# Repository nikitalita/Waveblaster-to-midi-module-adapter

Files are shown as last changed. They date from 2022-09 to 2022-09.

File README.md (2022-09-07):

# Waveblaster Breakout Card
A waveblaster breakout card to enable the use of external midi modules on sound cards:
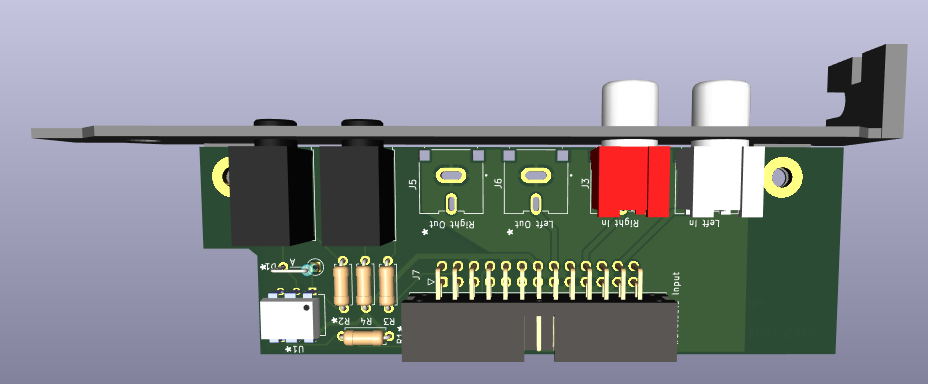
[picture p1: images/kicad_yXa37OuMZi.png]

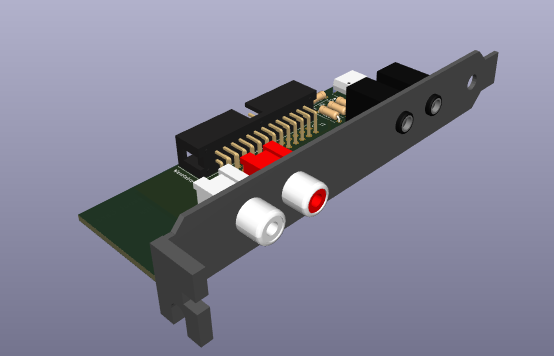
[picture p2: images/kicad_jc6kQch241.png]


Tested and working; here's the BOM:

| Id | Designator | Package | Quantity | Designation | Mouser: |
| ---- | --- | --- | --- | --- | --- |
| 1 | J7 | IDC-Header_2x13_P2.54mm_Horizontal-reversed | 1 | Wavetable Input | [5103310-6](https://www.mouser.com/ProductDetail/TE-Connectivity/5103310-6) |
| 2 | J1 | Jack_3.5mm_CUI_SJ1-3533NG_Horizontal | 1 | Midi Out | [490-SJ1-3533NG](https://www.mouser.com/ProductDetail/490-SJ1-3533NG) |
| 3 | R4,R3 | 220R THT resistor | 2 | 220R | |
| 4 | J3 | CUI_RCJ-042 | 1 | Right In | [490-RCJ-042](https://www.mouser.com/ProductDetail/490-RCJ-042) |
| 5 | J4 | CUI_RCJ-043 | 1 | Left In | [490-RCJ-043](https://www.mouser.com/ProductDetail/490-RCJ-043) |

For the header, you also can just use 2.54mm pitch double row right angle header pins. For the resistors, just buy a through-hole resistor sample book on Amazon or something.

If you want to add on the midi in port (most sound cards do not have this connected), add:

- 1x H11L1M optocoupler : https://www.mouser.com/ProductDetail/onsemi-Fairchild/H11L1M
- 1x 220 Ohm THT Resistor
- 1x 280 Ohm THT Resistor
- 1x 1N4148 THT Diode: https://www.mouser.com/ProductDetail/onsemi-Fairchild/1N4148

It's not advised to add on the audio output ports (for audio input into the synth), as only ONE sound card is known to make use of these: the MediaTriX AudioTriX 3D-XG, and it is very rare.

For the MIDI ports, you want a Type "A" 3.5mm to DIN adapter, like this one: https://www.amazon.com/ZAWDIO-Breakout-LittleBits-Female-Electribe/dp/B08WHSP7ZL/
Make sure that it is not Type "B", as this type will not work.

For the ribbon cable to connect the waveblaster header, Just use a 26 pin IDC cable. This one worked well for me: https://www.amazon.com/gp/product/B01AG9GXV4/ref=ppx_yo_dt_b_asin_title_o02_s00?ie=UTF8&psc=1

For the bracket, use the stencil file in bracket to 3D print it out. If you decide to make a metal one, be sure to add insulating rubber rings between the ports and the bracket, as this board is not intended to be grounded to the case.

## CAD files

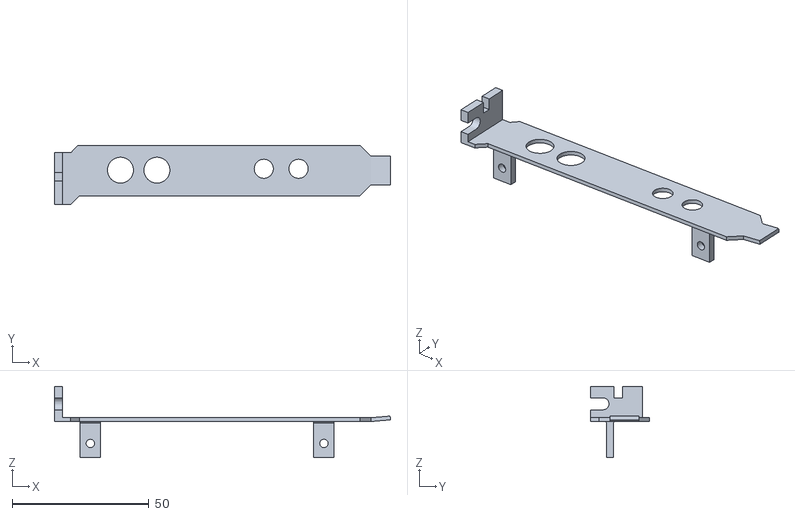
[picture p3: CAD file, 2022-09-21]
bracket/bracket.stl
122.8 x 21.6 x 26.0

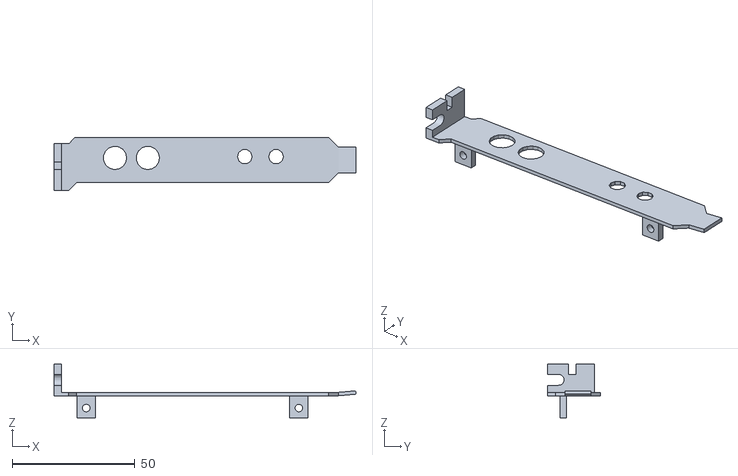
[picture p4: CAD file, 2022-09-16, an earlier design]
bracket/bracket-old.stl
122.8 x 21.6 x 21.8

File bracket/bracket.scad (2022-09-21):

resolution=32; // $fn
low_profile=0; // [0:false, 1:true]
bracket_thickness = 1.4; // base bracket depth

//Some 3d printers may have trouble with this, disable it if yours does.
angled_bottom_tab = 1; // [0:false, 1:true]
decorative_hole=0; // [0:false, 1:true]
// This puts the tabs at the top rather than the bottom, and hole y-offsets are adjusted accordingly
isa_slot=0; // [0:false, 1:true]
// This is used to calculate the y-offsets of the holes if the screw mount tabs are on the bottom
pcb_thickness=1.6;

top_tab_thickness = 3;

/* [Screw mount tabs] */

first_screw_tab_enabled = 1; // [0:false, 1:true]
second_screw_tab_enabled = 1; // [0:false, 1:true]
screw_mounts_on_bottom_of_pcb = 0; // [0:false, 1:true]
screw_mount_width = 7.5;
screw_mount_depth = 2.5;
screw_mount_hole_r = 1.55; // m3 bolt
screw_mount_thread_distance_base = 8;
screw_mount_inset_r = 2.9; // m3 bolt head
screw_mount_inset_depth = 0;
screw_mount_caulking = 0.5;

first_mount_x = 10.11;
mount_hole_distance = 85.4;
// If on top of the PCB, it is recommended to have this be at least the thickness of the PCB
screw_mount_y = 2.7;
second_mount_x = first_mount_x + mount_hole_distance;

/* [Round Holes] */
hole_1_enabled = 1; // [0:false, 1:true]
// X is offset from the first screw hole (i.e. the screw hole closest to the case mount cutout)
hole_1_x = 11.01;
// Y is offset from top of pcb
hole_1_y = 6.7;
hole_1_d = 9.5;

hole_2_enabled = 1; // [0:false, 1:true]
hole_2_x = 24.34;
hole_2_y = 6.7;
hole_2_d = 9.5;

hole_3_enabled = 1; // [0:false, 1:true]
hole_3_x = 63.41;
hole_3_y = 7.2;
hole_3_d = 6;

hole_4_enabled = 1; // [0:false, 1:true]
hole_4_x = 76.12;
hole_4_y = 7.2;
hole_4_d = 6;

hole_5_enabled = 0; // [0:false, 1:true]
hole_5_x = 37.69;
hole_5_y = 6.7;
hole_5_d = 9.5;

hole_6_enabled = 0; // [0:false, 1:true]
hole_6_x = 51.04;
hole_6_y = 6.7;
hole_6_d = 9.5;

/* [Rectangular Holes] */
// hole is at center of x,y positions
rectangular_hole_1_enabled = 0; // [0:false, 1:true]
// X is offset from the first screw hole (i.e. the screw hole closest to the case mount cutout)
rectangular_hole_1_x = 11.01;
// Y is offset from top of pcb
rectangular_hole_1_y = 6.5;
rectangular_hole_1_w = 10.5;
rectangular_hole_1_h = 10.5;

rectangular_hole_2_enabled = 0; // [0:false, 1:true]
rectangular_hole_2_x = 24.34;
rectangular_hole_2_y = 6.5;
rectangular_hole_2_w = 10.5;
rectangular_hole_2_h = 10.5;

rectangular_hole_3_enabled = 0; // [0:false, 1:true]
rectangular_hole_3_x = 63.41;
rectangular_hole_3_y = 7;
rectangular_hole_3_w = 10.5;
rectangular_hole_3_h = 10.5;

rectangular_hole_4_enabled = 0; // [0:false, 1:true]
rectangular_hole_4_x = 76.12;
rectangular_hole_4_y = 7;
rectangular_hole_4_w = 10.5;
rectangular_hole_4_h = 10.5;

rectangular_hole_5_enabled = 0; // [0:false, 1:true]
rectangular_hole_5_x = 37.69;
rectangular_hole_5_y = 6.5;
rectangular_hole_5_w = 10.5;
rectangular_hole_5_h = 10.5;

rectangular_hole_6_enabled = 0; // [0:false, 1:true]
rectangular_hole_6_x = 51.04;
rectangular_hole_6_y = 6.5;
rectangular_hole_6_w = 10.5;
rectangular_hole_6_h = 10.5;
// values taken from https://content.norcomp.net/rohspdfs/Connectors/PanelCutOuts/Panel_Cutout_D-Sub-Single.pdf

/* [D-Sub holes (Serial/VGA/Gameport)] */
// hole is at center of x,y positions
dsub_hole_1_type = 0; // [0:None, 15.46:DB-9(VGA/Serial), 23.79:DB-15(Gameport), 37.51:DB-25(Parallel)]
// X is offset from the first screw hole (i.e. the screw hole closest to the case mount cutout)
dsub_hole_1_x = 37.6;
// Y is offset from top of pcb
dsub_hole_1_y = 7.1;
dsub_hole_1_invert = 0; // [0:false, 1:true]

dsub_hole_2_type = 0; // [0:None, 15.46:DB-9(VGA/Serial), 23.79:DB-15(Gameport), 37.51:DB-25(Parallel)]
dsub_hole_2_x = 37.6;
dsub_hole_2_y = 7.1;
dsub_hole_2_invert = 0; // [0:false, 1:true]

dsub_hole_3_type = 0; // [0:None, 15.46:DB-9(VGA/Serial), 23.79:DB-15(Gameport), 37.51:DB-25(Parallel)]
dsub_hole_3_x = 37.6;
dsub_hole_3_y = 7.1;
dsub_hole_3_invert = 0; // [0:false, 1:true]

/* [DVI Hole]] */

dvi_hole_enabled = 0; // [0:false, 1:true]
dvi_hole_x = 37.6;
dvi_hole_y = 6;
dvi_hole_invert = 0; // [0:false, 1:true]


module __Customizer_Limit__ () {}  // This actually works
shown_by_customizer = 0; // [0:false, 1:true]

$fn = resolution;
bracket_width_length = low_profile? 71.46 : 112.78;
bracket_length = low_profile ? 79.20 : 120.02;
bracket_width = 18.42 + 0;
bottom_tab_width = 10.19 + 0;
bracket_bottom_tab_angle_length = (bracket_width - bottom_tab_width) / 2;

bracket_reinforce_width = bracket_width * .2;
bracket_reinforce_length = bracket_length * .78;

bracket_hole_dia = decorative_hole ? 4.75 : 0;
bracket_hole_distance = low_profile ? 66.19 : 107.01;

screw_mount_thread_distance = screw_mount_thread_distance_base + bracket_thickness;
screw_mount_length = screw_mount_thread_distance * 1.4 + bracket_thickness;

bracket_reinforce_depth = 0;
bracket_reinforce_offset_x = -6;
bracket_reinforce_offset_y = -5;

// top notch
notch_width = 2.54;
notch_length = 3.94-.86; // 3.94 - specified thickness of .86mm (vs actual thickness)

top_tab_width = 19.05; // had to fudge this
top_tab_length = 11.43;
top_tab_x = 0;
top_tab_y = 3.17; // 21.59 - 18.42
top_tab_screw_groove_dia = 4.42;
top_tab_screw_groove_fudge = -0.4; // kinda came out looking wrong so I'm faking it a bit here
top_tab_screw_groove_center = 3.18 + top_tab_screw_groove_fudge;
top_tab_screw_groove_distance = 6.35;
top_tab_screw_groove_translate_z = top_tab_length - top_tab_screw_groove_dia / 2 - top_tab_screw_groove_distance;

top_tab_useless_notch_length = 3.05;
top_tab_useless_notch_width = top_tab_screw_groove_distance - top_tab_screw_groove_dia / 2;
top_tab_useless_notch_z = top_tab_length - top_tab_useless_notch_width;
top_tab_useless_notch_y = top_tab_useless_notch_width / 2 + 8.05 - top_tab_useless_notch_length / 2;


module prism(l, w, h){
     polyhedron(
         points=[[0,0,0], [l,0,0], [l,w,0], [0,w,0], [0,w,h], [l,w,h]],
         faces=[[0,1,2,3],[5,4,3,2],[0,4,5,1],[0,3,4],[5,2,1]]
         );
}
// screw mounts
module screwmount(x) {
  
  translate([0, isa_slot? -screw_mount_y - screw_mount_depth : -bracket_width + screw_mount_y, 0]) // easier to be explicit here than factor it in the below statement
  translate([x - screw_mount_width / 2, bracket_width, -screw_mount_length + bracket_thickness])
    // cut out the threads
    difference() {
      union() {
        cube([screw_mount_width, screw_mount_depth, screw_mount_length]);
        //top caulking
        if ((isa_slot && bracket_width-screw_mount_y +screw_mount_caulking < bracket_width) || (!isa_slot &&  screw_mount_y + screw_mount_depth+ screw_mount_caulking < bracket_width)){
        difference(){
        translate([screw_mount_width, screw_mount_depth-.05, screw_mount_length-bracket_thickness-screw_mount_caulking +.05])
          rotate([90,0,180])
          prism(screw_mount_width,screw_mount_caulking+.05,screw_mount_caulking+.05);
        }
        }
        //bottom caulking
        if ((isa_slot && bracket_width-screw_mount_y -screw_mount_depth -screw_mount_caulking > 0) || (!isa_slot && screw_mount_y - screw_mount_caulking > 0)){
        translate([0, 0, screw_mount_length-bracket_thickness-screw_mount_caulking +.05])
          rotate([90,0,0])
          prism(screw_mount_width,screw_mount_caulking+.05,screw_mount_caulking+.05);
        }        
      }
       translate([screw_mount_width / 2, -2, screw_mount_length - screw_mount_thread_distance])
         rotate([0, 90, 90]) cylinder(r=screw_mount_hole_r, h=10, $fn=20);
      //inset
      translate([screw_mount_width / 2, ((isa_slot && screw_mounts_on_bottom_of_pcb) || (!isa_slot && !screw_mounts_on_bottom_of_pcb))?(screw_mount_depth - screw_mount_inset_depth + 0.01):(-0.01),
        screw_mount_length - screw_mount_thread_distance])
          rotate([0, 90, 90])
          cylinder(r=screw_mount_inset_r, h=screw_mount_inset_depth, $fn=20);
    }
}

module translate_hole(hole_x,hole_y){
  y_offset_b = screw_mounts_on_bottom_of_pcb ? pcb_thickness + screw_mount_depth : 0;
  y_offset = !isa_slot ? 
    hole_y + screw_mount_y + y_offset_b
    : bracket_width - (hole_y + screw_mount_y + y_offset_b);
  translate([first_mount_x+ hole_x, y_offset, -bracket_thickness])
    children();
}
module round_hole(hole_x,hole_y,hole_d){
  translate_hole(hole_x,hole_y)
    cylinder(10,hole_d/2,hole_d/2);
}
module rectangular_hole(hole_x,hole_y,hole_w,hole_h){
  translate_hole(hole_x,hole_y)
    cube([10, hole_w, hole_h], center=true);
}
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

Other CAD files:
kicad/bracket.step

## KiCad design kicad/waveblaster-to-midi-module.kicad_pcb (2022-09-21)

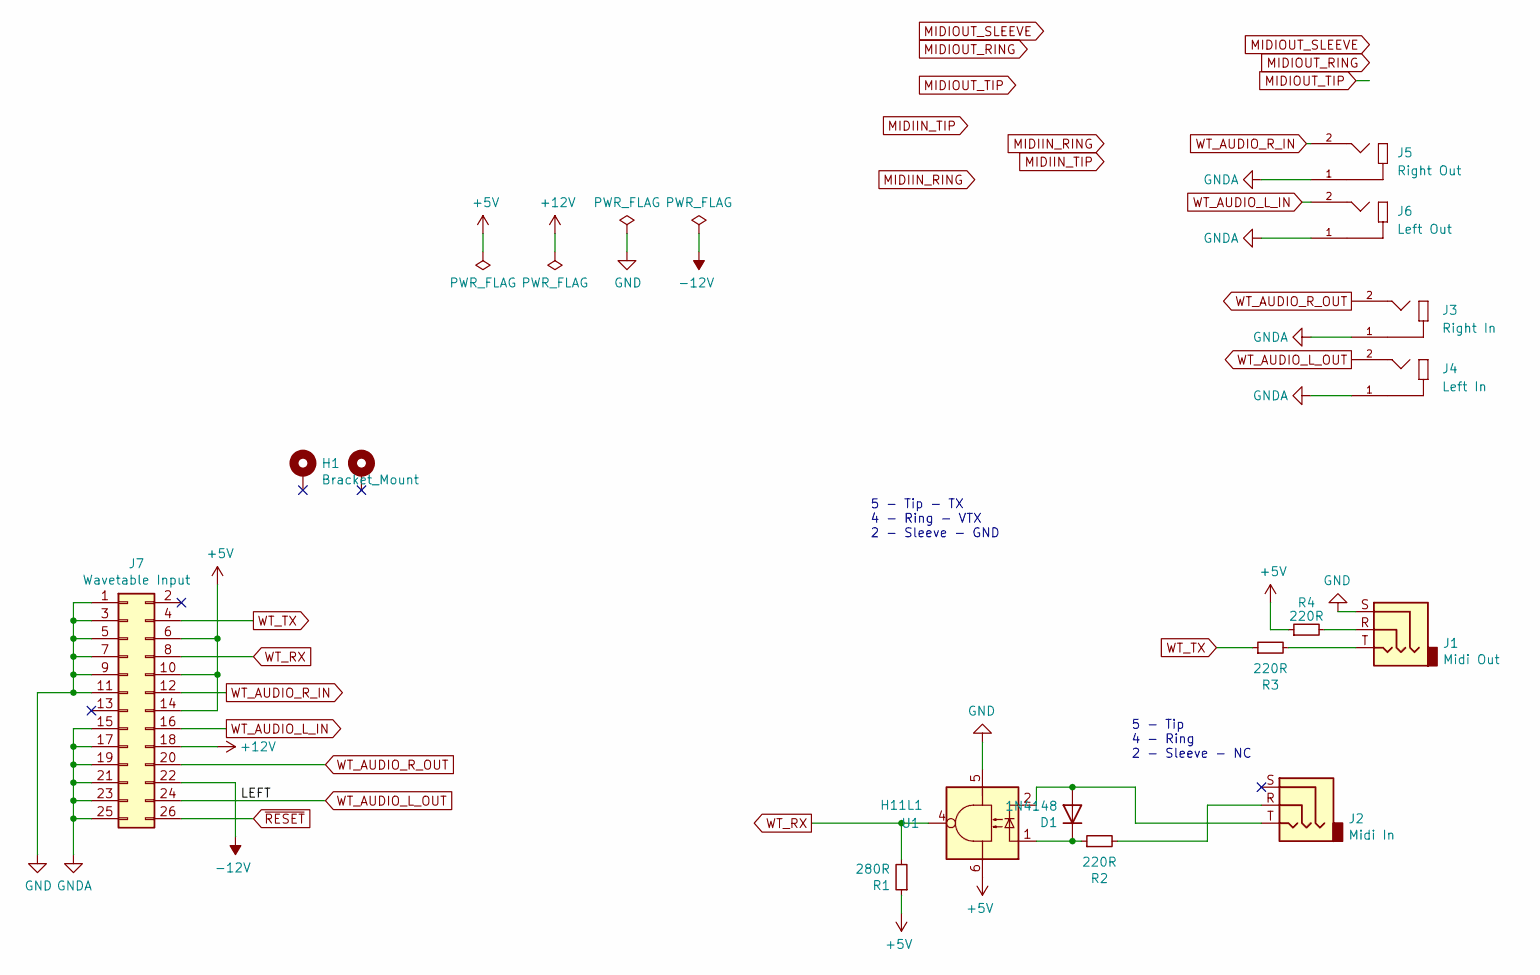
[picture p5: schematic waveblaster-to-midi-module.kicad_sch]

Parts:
D1: 1N4148; D_DO-35_SOD27_P5.08mm_Vertical_AnodeUp
H1: Bracket_Mount; bracket footprint
J1: Midi Out; Jack_3.5mm_CUI_SJ1-3533NG_Horizontal
J2: Midi In; Jack_3.5mm_CUI_SJ1-3533NG_Horizontal
J3: Right In; CUI_RCJ-04X
J4: Left In; CUI_RCJ-043
J5: Right Out; CUI_RCJ-04X
J6: Left Out; CUI_RCJ-043
J7: Wavetable Input; IDC-Header_2x13_P2.54mm_Horizontal-reversed
R1: 280R; R_Axial_DIN0207_L6.3mm_D2.5mm_P7.62mm_Horizontal; Mouser 667-ERJ-6ENF1002V
R2, R3, R4: 220R; R_Axial_DIN0207_L6.3mm_D2.5mm_P7.62mm_Horizontal; Mouser 667-ERJ-6ENF2200V
U1: H11L1; H11L1M-DIP8

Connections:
+5V: J7.6, J7.10, J7.14, R1.1, R4.1, U1.6
+12V: J7.18
-12V: J7.22
GND: J1.S, J7.1, J7.3, J7.5, J7.7, J7.9, J7.11, U1.5
GNDA: J3.1, J4.1, J5.1, J6.1, J7.15, J7.17, J7.19, J7.21, J7.23, J7.25
unnamed: D1.1 (K), R2.1, U1.1
unnamed: D1.2 (A), J2.T, U1.2
unnamed: J1.R, R4.2
unnamed: J1.T, R3.2
unnamed: J2.R, R2.2
WT_AUDIO_L_IN: J6.2, J7.16
WT_AUDIO_L_OUT: J4.2, J7.24
WT_AUDIO_R_IN: J5.2, J7.12
WT_AUDIO_R_OUT: J3.2, J7.20
WT_RX: J7.8, R1.2, U1.4
WT_TX: J7.4, R3.1
~RESET: J7.26

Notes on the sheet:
5 - Tip 4 - Ring 2 - Sleeve - NC
5 - Tip - TX 4 - Ring - VTX 2 - Sleeve - GND

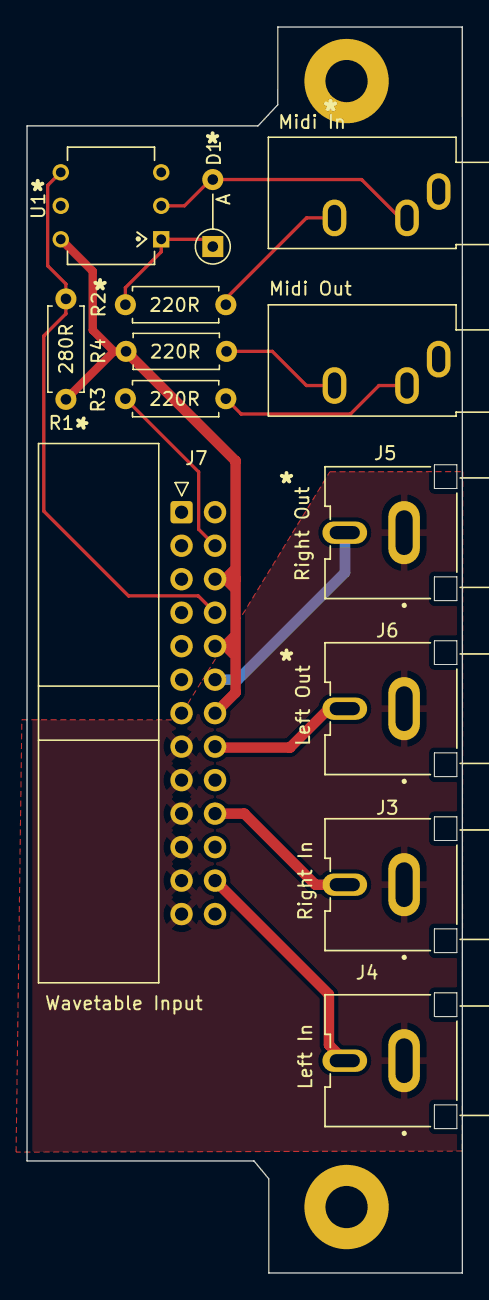
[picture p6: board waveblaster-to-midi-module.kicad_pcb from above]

Board: 2 copper layers, 33.0 x 94.5 mm, 14 parts (0 on the bottom side), 14 nets.

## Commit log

2022-09-07 final board revision, update readme
    [waveblaster-to-midi-module.kicad_pcb]
2022-09-08 Adjust outline of PCB, finalize bracket
    [bracket.scad, bracket.stl, waveblaster-to-midi-module.kicad_pcb]
2022-09-08 regenerate gerbers
    [waveblaster-to-midi-module-CuBottom.gbr, waveblaster-to-midi-module-CuTop.gbr, waveblaster-to-midi-module-EdgeCuts.gbr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]
2022-09-16 fix clearance issues, fix bracket
    [bracket-old.stl, bracket.scad, bracket.stl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]
2022-09-21 Fix bracket, update bracket footprint, update JLCPCB gerbers
    [bracket.scad, bracket.step, bracket.stl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]
